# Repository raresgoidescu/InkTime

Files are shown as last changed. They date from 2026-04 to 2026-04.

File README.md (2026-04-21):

<!-- Copyright GOIDESCU Rareș-Ștefan 2026 -->

# InkTime

InkTime is a proper solution for the people that can't be bothered to charge their watch daily. This is a beginner's attempt at implementing it. Please see [the disclaimer and the license](#trademark-disclaimer) notice.

## Block Diagram

Block Diagram Image

## Bill of Materials

| Part / Value | Refs | Qty | Procurement | Datasheet |
| :--- | :--- | :---: | :--- | :--- |
| **Active ICs & Semiconductors** | | | | |
| nRF52840-QFAA Microcontroller | U1 | 1 | [DigiKey](https://www.digikey.be/en/products/detail/nordic-semiconductor-asa/NRF52840-QFAA-F-R/15929812) | [DS](https://www.nordicsemi.com/Products/nRF52840) |
| BMA423 Triaxial Accelerometer | IC3 | 1 |[Mouser 262-BMA423](https://eu.mouser.com/ProductDetail/Bosch-Sensortec/BMA423?qs=HXFqYaX1Q2xC%252BSgeGoX3mg%3D%3D) | [DS](https://watchy.sqfmi.com/assets/files/BST-BMA423-DS000-1509600-950150f51058597a6234dd3eaafbb1f0.pdf) |
| BQ25180YBGR Li-Ion Charger | IC1 | 1 |[Mouser 595-BQ25180YBGR](https://eu.mouser.com/ProductDetail/Texas-Instruments/BQ25180YBGR?qs=doiCPypUmgEWjAK%252BJAX6Tw%3D%3D) | [DS](https://www.ti.com/product/BQ25180) |
| DRV2605YZFR Haptic Driver | IC2 | 1 | [Mouser](https://eu.mouser.com/ProductDetail/Texas-Instruments/DRV2605YZFR?qs=9Zb5cNRUa0Ym539PjgFm3g%3D%3D) | [DS](https://www.ti.com/product/DRV2605) |
| MAX17048G+T10 Fuel Gauge | U3 | 1 | [DigiKey](https://www.digikey.com/en/products/detail/analog-devices-inc-maxim-integrated/MAX17048G-T10/3758921) | [DS](https://www.analog.com/en/products/max17048.html) |
| RT6160AWSC Buck-Boost DC-DC | IC9 | 1 |[Mouser 835-RT6160AWSC](https://eu.mouser.com/ProductDetail/Richtek/RT6160AWSC?qs=amGC7iS6iy%2FLd9PSoixZXQ%3D%3D) | [DS](https://www.richtek.com/Products/Switching%20Regulators/Buck-Boost%20Converter/RT6160A) |
| USBLC6-2SC6Y ESD Protection | D3 | 1 | [DigiKey](https://www.digikey.com/en/products/detail/stmicroelectronics/USBLC6-2SC6Y/2819177) | [DS](https://www.st.com/en/protections-and-emi-filters/usblc6-2.html) |
| MBR0530 Schottky Diode | D2, D4, D5 | 3 | [Mouser](https://eu.mouser.com/c/semiconductors/discrete-semiconductors/diodes-rectifiers/schottky-diodes-rectifiers/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) | [DS](https://www.onsemi.com/pdf/datasheet/mbr0530t1-d.pdf) |
| DMG2305UX-7 P-CH MOSFET 20V/4.2A | Q1 | 1 | [Mouser](https://ro.mouser.com/ProductDetail/Diodes-Incorporated/DMG2305UX-7?qs=L1DZKBg7t5F%2FNBHrjfxC%252Bg%3D%3D) | [DS](https://www.diodes.com/assets/Datasheets/DMG2305UX.pdf) |
| SI1308EDL-T1-GE3 N-CH MOSFET 30V/1.5A | Q3 | 1 | [Mouser](https://eu.mouser.com/ProductDetail/Vishay-Semiconductors/SI1308EDL-T1-GE3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) |[DS](https://www.vishay.com/docs/63399/si1308edl.pdf) |
| **Connectors & Electromechanical** | | | | |
| 2450AT18B100E 2.45 GHz Antenna | ANT1 | 1 | [Mouser 609-2450AT18B100E](https://www.mouser.co.uk/ProductDetail/Johanson-Technology/2450AT18B100E?qs=yCnrNFeXz%252Bh5MFsFIXGZGA%3D%3D) | [DS](https://www.johansontechnology.com/datasheets/2450AT18B100/2450AT18B100.pdf) |
| 503480-2400 24-pin FPC 0.5 mm | J1 | 1 |[Mouser 538-503480-2400](https://eu.mouser.com/ProductDetail/Molex/503480-2400?qs=OAhjpuo3Vu7efIoxFh9AOw%3D%3D) | [DS](https://www.molex.com/en-us/products/part-detail/5034802400?display=pdf) |
| KH-TYPE-C-16P USB Type-C 16-pin | J4 | 1 | [xonelec.com](https://www.xonelec.com/mpn/kinghelm/khtypec16p) | [DS](https://xonstorage.z8.web.core.windows.net/pdf/kinghelm_khtypec16p_xonjuly20_20_link.pdf) |
| TC2030-IDC 6-pin Debug Adapter | J2 | 1 | [Tag-Connect](https://www.tag-connect.com/product/tc2030-idc-6-pin-tag-connect-plug-of-nails-spring-pin-cable-with-legs) | [DS](https://www.tag-connect.com/wp-content/uploads/bsk-pdf-manager/2019/12/TC2030-IDC-Datasheet-Rev-B.pdf) |
| EVP-AKE31A Tactile Button | SW_DN, SW_ENT, SW_UP | 3 |[Mouser](https://eu.mouser.com/ProductDetail/Panasonic/EVP-AKE31A?qs=EU6FO9ffTwe%252BJzX5LvvHqA%3D%3D) | [DS](https://www.tme.eu/Document/7d6137f818fadb8daa876cedb29b6731/EVPAKseries.pdf) |
| **Inductors** | | | | |
| FTC252012SR47MBCA 0.47 µH | L7 | 1 |[LCSC C5832368](https://www.lcsc.com/product-detail/C5832368.html) | [DS](https://www.lcsc.com/datasheet/C5832368.pdf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) |
| 744043680 68 µH | L5 | 1 |[Mouser](https://eu.mouser.com/ProductDetail/Wurth-Elektronik/744043680?qs=PGXP4M47uW6VkZq%252BkzjrHA%3D%3D) | [DS](https://www.we-online.com/katalog/datasheet/744043680.pdf) |
| **Passives** | | | | |
| 12 pF 0201 (HFXO/LFXO load caps) | C1, C2, C17, C18 | 4 | Generic 0201 | - |
| 100 nF 0201 decoupling | C5, C7, C8, C12, C19 | 5 | Generic 0201 | - |
| 1 µF 0201[GRM011R60J152KE01L](https://www.snapeda.com/parts/GRM011R60J152KE01L/Murata/view-part/) | C29–C32, C37, C38 | 6 | Murata / Mouser | - |
| 0.1 µF 0201[GRM011R60J152KE01L](https://www.snapeda.com/parts/GRM011R60J152KE01L/Murata/view-part/) | C23, C27, C34, C42 | 4 | Murata / Mouser | - |
| 10 µF 0402 | C24, C39, C1-EP-DR | 3 | Generic 0402 | - |
| 22 µF 0402 | C25, C33 | 2 | Generic 0402 | - |
| 1 µF/50V 0402 (EPD drive) | EPD_C1/2/6–12 | 9 | Generic 0402 | - |
| 3.3 kΩ 0201 (I2C pull-ups) | R17, R18 | 2 | Generic 0201 | - |
| 5.1 kΩ 0201 (USB CC) | R1_USB, R2_USB | 2 | Generic 0201 | - |
| 10 kΩ 0201 (button pull-ups, misc) | R5, R7, R8, R9, R2_EP_DR, R_PWR_EPD | 6 | Generic 0201 | - |
| 0 Ω 0201 (DNP jumpers) | R2, R3, R4 | 3 | Generic 0201 | - |

## Hardware Description

### Power Management

**BQ25180YBGR** charges the LiPo from USB (5V). `PMIC_INT` alerts the MCU to faults and status changes. Q1 provides reverse-polarity protection on the VBUS path.

**RT6160AWSC** generates the 3V3 rail via a buck-boost topology, required because battery voltage (3V–4V2) straddles the 3V3 output. Switching node uses an inductor; output is filtered by capacitors. Controlled via I2C and a GPIO enable pin.

**MAX17048G+T10** estimates battery SoC over I2C using the ModelGauge algorithm, eliminating the need for a power-wasting current-sense resistor. The `ALERT` pin fires when the SoC drops below a configurable threshold.

**MBR0530 diodes** (D2, D4, D5) are arranged to steer power between USB, the battery, and the EPD drive rail to prevent back-feeding across power domains.

### Microcontroller

64 MHz Cortex-M4F, 1 MB Flash, 256 KB RAM, Bluetooth 5.0 LE, USB 2.0 FS. Peripherals used:

- **Power** - The internal DC-DC regulator is enabled via dedicated LC matching to step down the 3V3 rail internally, drastically reducing the active power footprint of the CPU and radio.
- **SPIM3** - E-Paper display (MOSI, SCK + 4 control GPIOs)
- **TWIM0** - shared I2C bus (BMA423, BQ25180, MAX17048, DRV2605, RT6160A)
- **USB** - firmware update / serial via dedicated D+/D− pads through USBLC6 ESD protection
- **RTC0** - timekeeping in sleep, clocked from 32.768 kHz LFXO
- **Radio** - Bluetooth LE for phone time sync

### Clocks

- X1 (32 MHz) - HFXO for CPU and radio. 12 pF load caps C1, C2 placed adjacent.
- X2 (32.768 kHz) - LFXO for RTC. Pins P0.00/XL1 and P0.01/XL2. 12 pF load caps C17, C18.

### Antenna

The 2450AT18B100E chip antenna sits at the board edge with the full copper/trace keep-out zone underneath per the datasheet.
It connects via a matching network.

### Display (SPI)

Molex 503480-2400 24-pin 0.5 mm FPC connector (J1) on the left board edge.
Interface: MOSI, SCK, EPD_CS, EPD_DC, EPD_RST, EPD_BUSY over SPIM3.
The on-board boost drive circuit generates the positive and negative high-voltage rails needed for pixel switching.
SJ1 solder jumper selects the EPD panel variant.

### IMU (I2C)

Step counting, tilt, tap detection, etc.

### Haptics (I2C)

DRV2605YZFR ERM/LRA haptic driver for physical notification feedback.

### Buttons

Three EVP-AKE31A side-entry tactile switches. Debounced via hardware using capacitors (C29–C32 series) and 10 kΩ pull-ups (R5, R7, R8) to ensure clean interrupts waking the MCU from deep sleep.

### Debug Interface

Tag-Connect 6-pin pogo footprint (J2). Signals: SWDIO, SWDCLK, SWO, RESET, VCC, GND.

## nRF52840 Pin Assignment

| Pin | Net | Peripheral | Notes |
| :--- | :--- | :--- | :--- |
| P0.00/XL1 | `XL1` | Crystal X2 | 32.768 kHz LFXO in |
| P0.01/XL2 | `XL2` | Crystal X2 | 32.768 kHz LFXO out |
| XC1, XC2 | `XC1`, `XC2` | Crystal X1 | 32 MHz HFXO |
| P0.06 | `SDA` | IC1, IC2, IC3, U3, IC9 | I2C |
| P0.07 | `SCL` | IC1, IC2, IC3, U3, IC9 | I2C |
| P0.08 | `IMU_INT1` | IMU (BMA421)	Interrupt 1 |
| P0.11	| `PMIC_INT` | LiPo Charger | Fault interrupt |
| P0.12	| `HAPTIC_EN`	| Haptics | Haptics enable |
| P0.13 | `P0.13` | SW_UP | Button |
| P0.14 | `P0.14` | SW_ENT | Button |
| P0.15	| `EPD_DC` | Display D/C |
| P0.16	| `EPD_RST` | Display reset |
| P0.17 | `EPD_BUSY` | Display | Busy status |
| P0.18/RESET | `RESET` | TC2030 J2, pull-up | system reset |
| SWDCLK | `SWDCLK` | TC2030 J2 | SWD clock |
| SWDIO | `SWDIO` | TC2030 J2 | SWD data |
| P1.00 | `SWO` | TP | SWO trace output |
| P1.02 | `P1.02` | SW_DN | Button |
| P1.08 | `IMU_INT2` | IMU | Interrupt 2 |
| P1.10 | `ALERT` | Fuel Gauge | SoC alert |
| D+ | `D+` | USB-C J4 via D3 | USB FS data + |
| D− | `D−` | USB-C J4 via D3 | USB FS data − |
| VBUS | `VBUS` | J4 / R1_USB+R2_USB divider | 5 V bus |
| ANT |	`RF` | 2.4 GHz antenna | Antenna feed |

## Power Consumption Estimates

| Mode | Dominant consumers | Est. current | Battery life (300 mAh) |
| :--- | :--- | ---: | ---: |
| Deep sleep (Static display, BLE off) | nRF52840 RTC + BMA423 sleep + MAX17048 + quiescent ICs | ~120 µA | ~104 days |
| Active (1 EPD refresh/min + BLE adv) | CPU active + Radio TX/RX + EPD boost circuit averaged | ~5–6 mA | ~50 hours |
| Mixed realistic use | Mostly deep sleep, periodic wake on wrist gesture / button press | - | **~7–14 days** |

## Design Logs

- Had to manually approve via in pad overlaps.
- Had to apply neck down to some segments of the power routes, reducing the width to 0.2675 mm (from 0.3 mm).
- Matched lenght for differential lines and symmetric configurations for the crystals.

## PCB Renders

### Top Layer

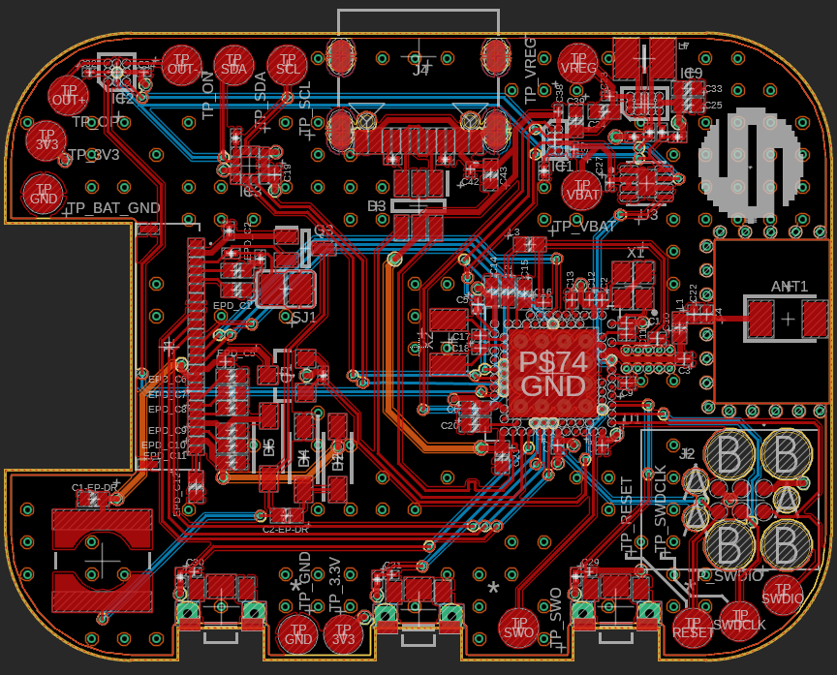
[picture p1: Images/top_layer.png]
PCB Top Layer


### Polygon Pours

| Top | Bottom |
|---|---|
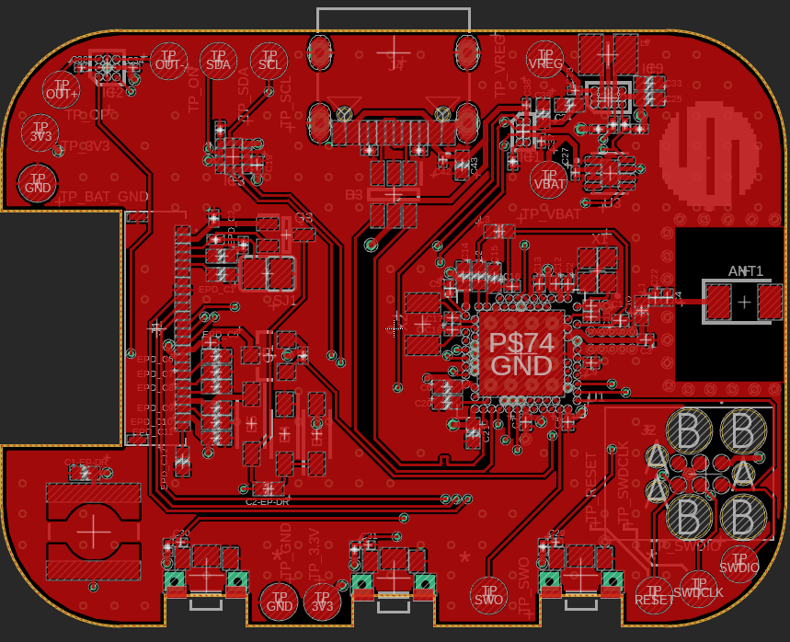
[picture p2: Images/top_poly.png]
top_poly
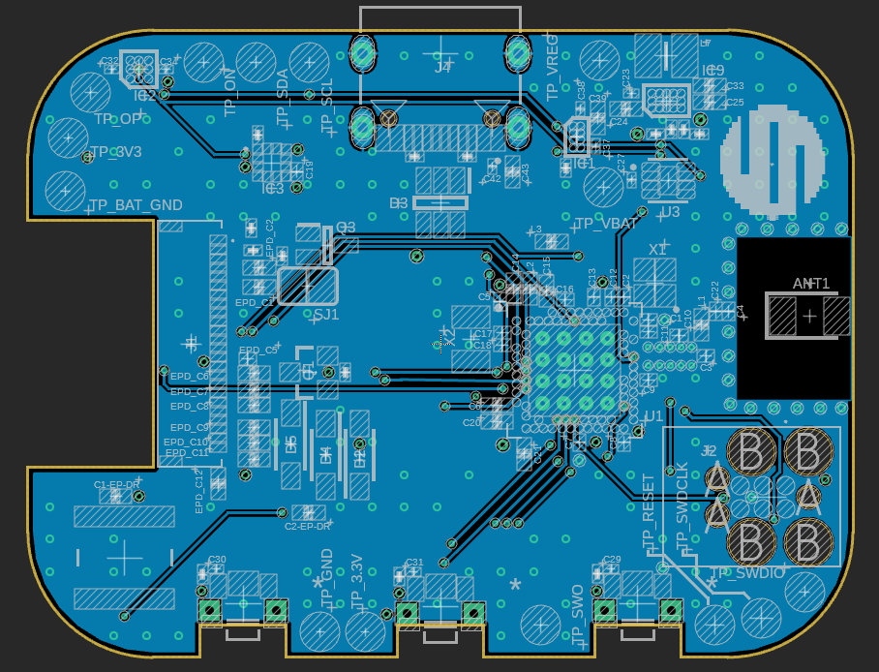
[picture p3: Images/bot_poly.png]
bot_poly
|  |  |

| GND | Power |
|---|---|
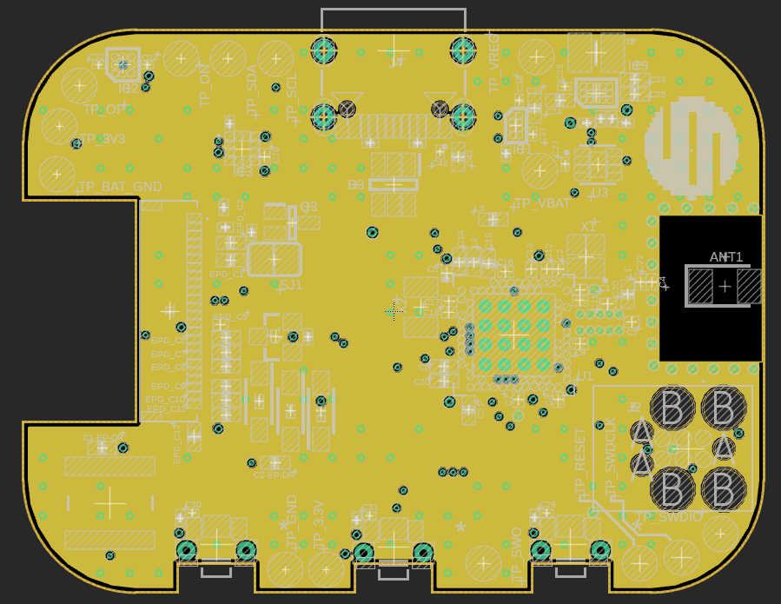
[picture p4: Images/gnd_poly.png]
gnd_poly
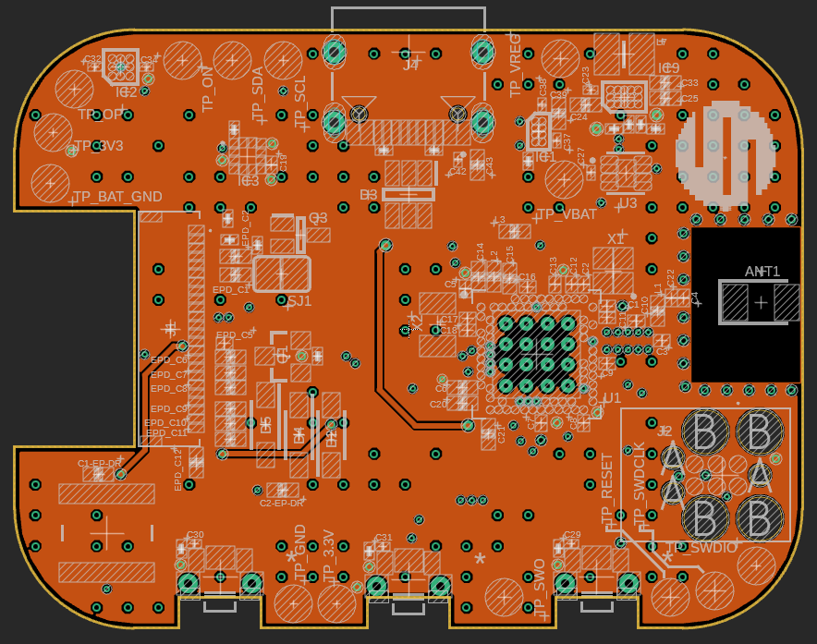
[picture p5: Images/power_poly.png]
power_poly
|  |  |

## Exploded View

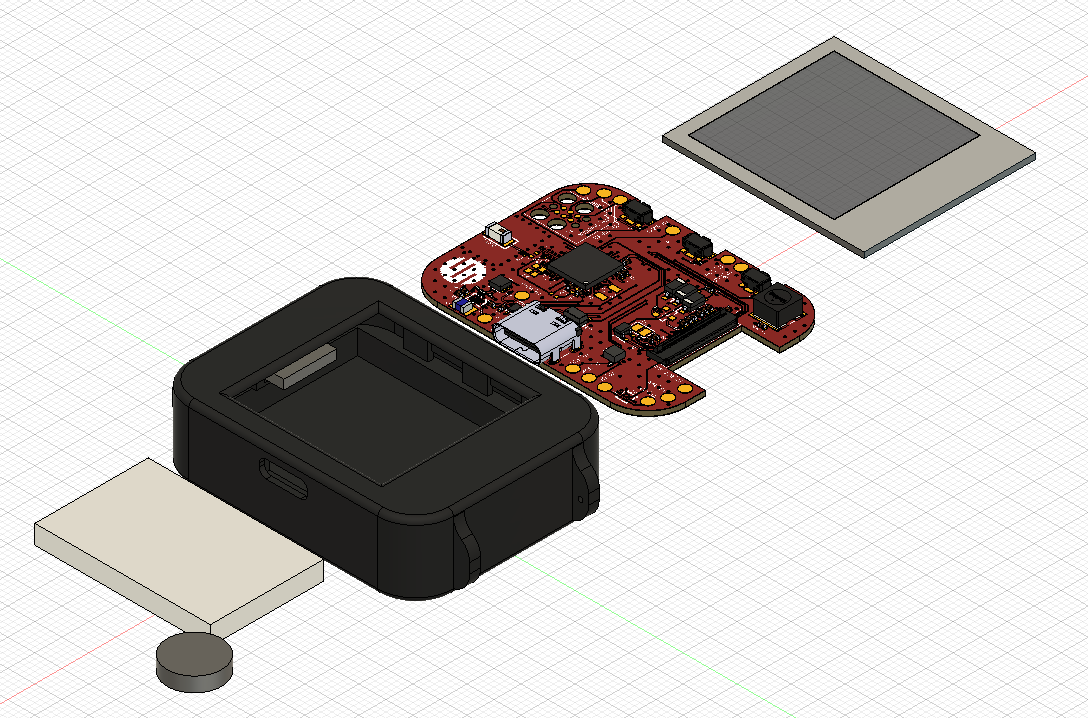
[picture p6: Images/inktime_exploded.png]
InkTimeExploded


## Trademark Disclaimer

This project includes a reproduction of the Viltrumite logo on the PCB silkscreen.

- The Viltrumite logo is trademark of Image Comics and/or its creators.
- This project is non-commercial and is not affiliated with, endorsed by, or sponsored by Image Comics or the Invincible franchise.
- The [CERN-OHL-S v2.0](LICENSE) license governs the electronic design files only and does not grant any rights to the Viltrumite trademark or associated artwork.

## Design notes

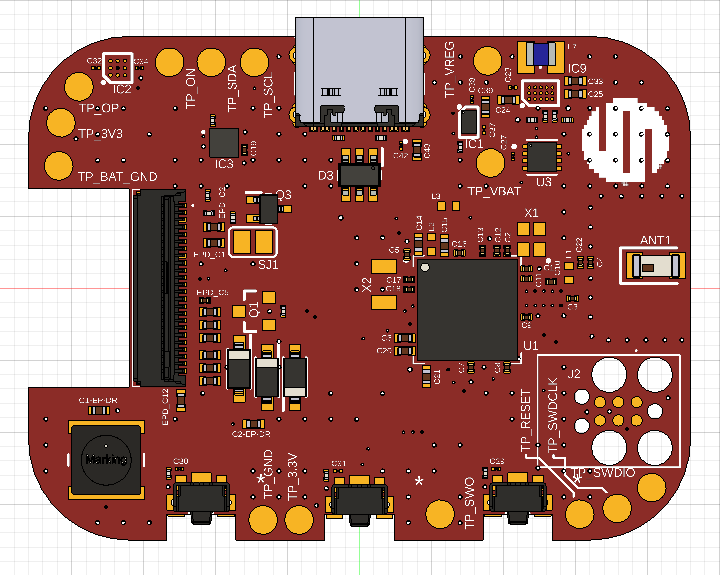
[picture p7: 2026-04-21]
Images/board-top.png

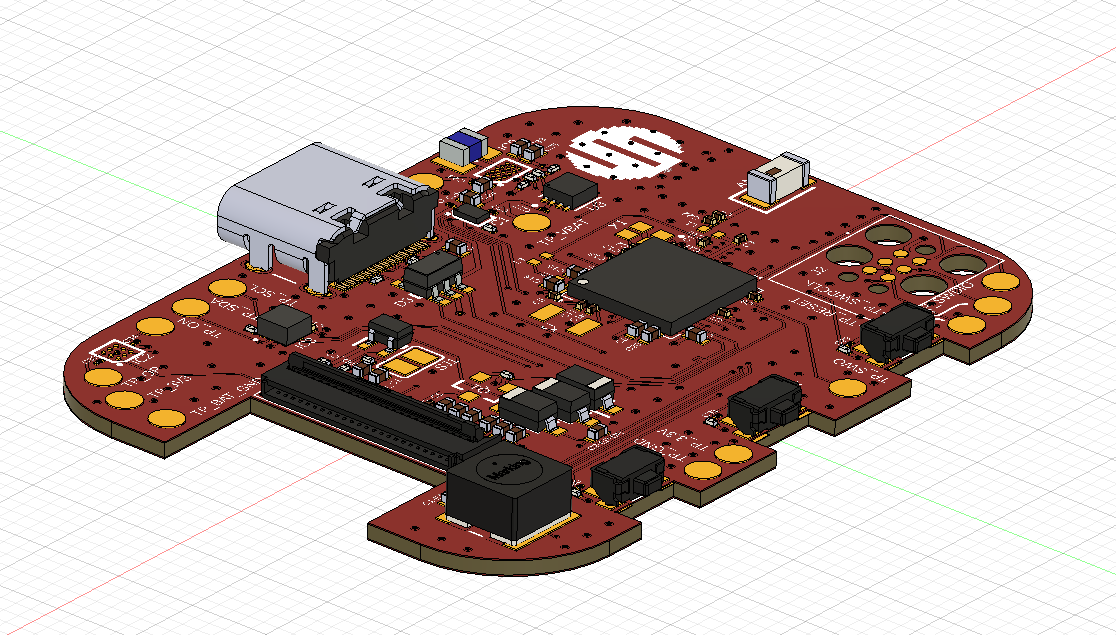
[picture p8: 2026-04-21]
Images/board-side.png

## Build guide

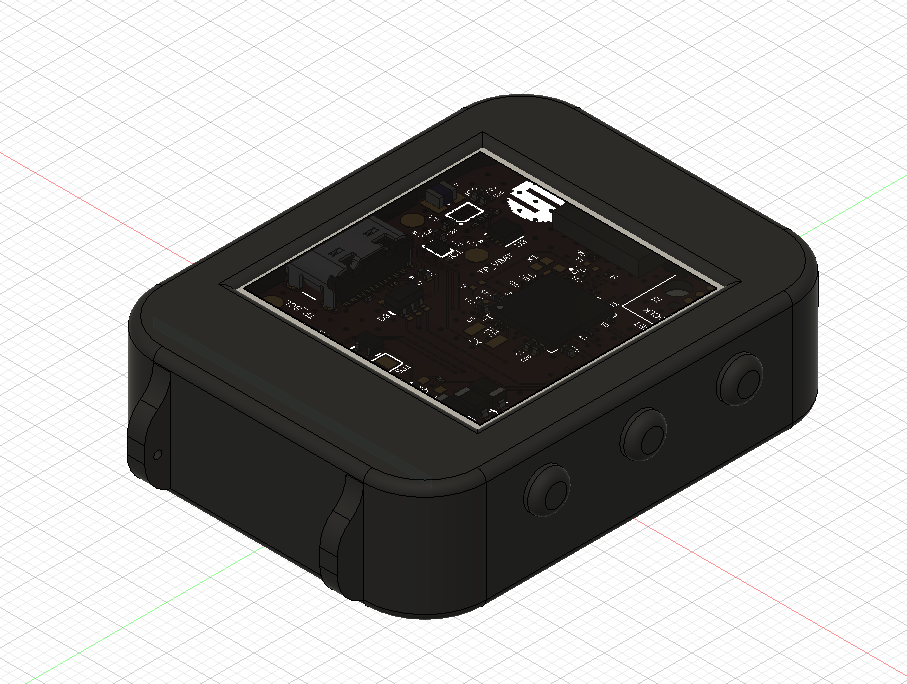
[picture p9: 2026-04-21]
Images/complete_assembly.png

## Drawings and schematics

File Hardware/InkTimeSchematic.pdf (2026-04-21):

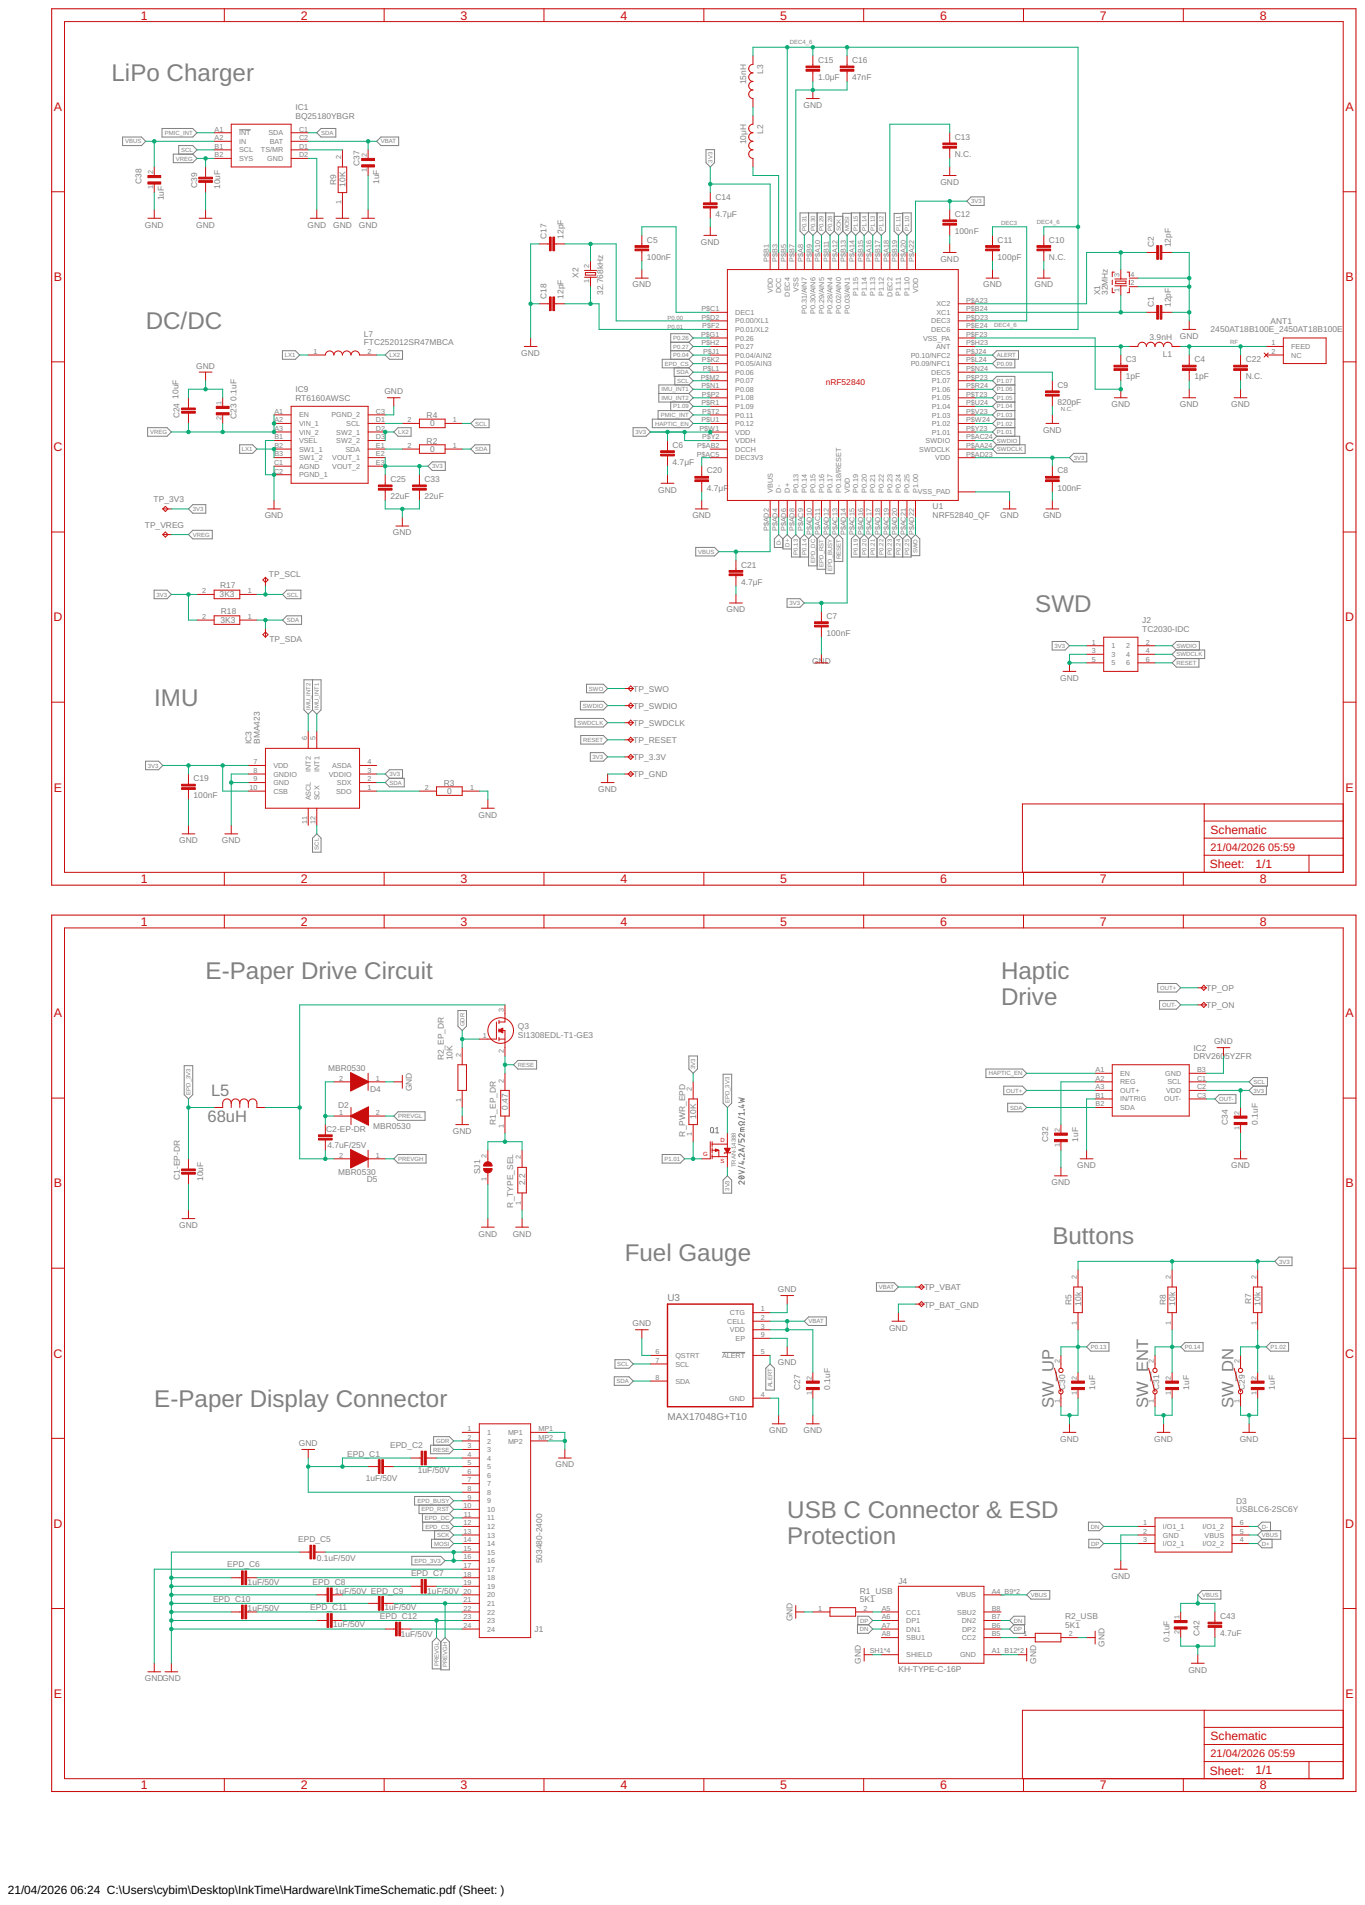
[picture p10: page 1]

1uF GND GND GND GND GND

EPD_C7 18

1uF/50V EPD_C8 | 19

EPD_C10 | | 21

1uF/50V EPD_C11 | 1uF/50V | 22

EPD_C12 | 23

21/04/2026 06:24 C:\Users\cybim\Desktop\InkTime\Hardware\InkTimeSchematic.pdf (Sheet: )

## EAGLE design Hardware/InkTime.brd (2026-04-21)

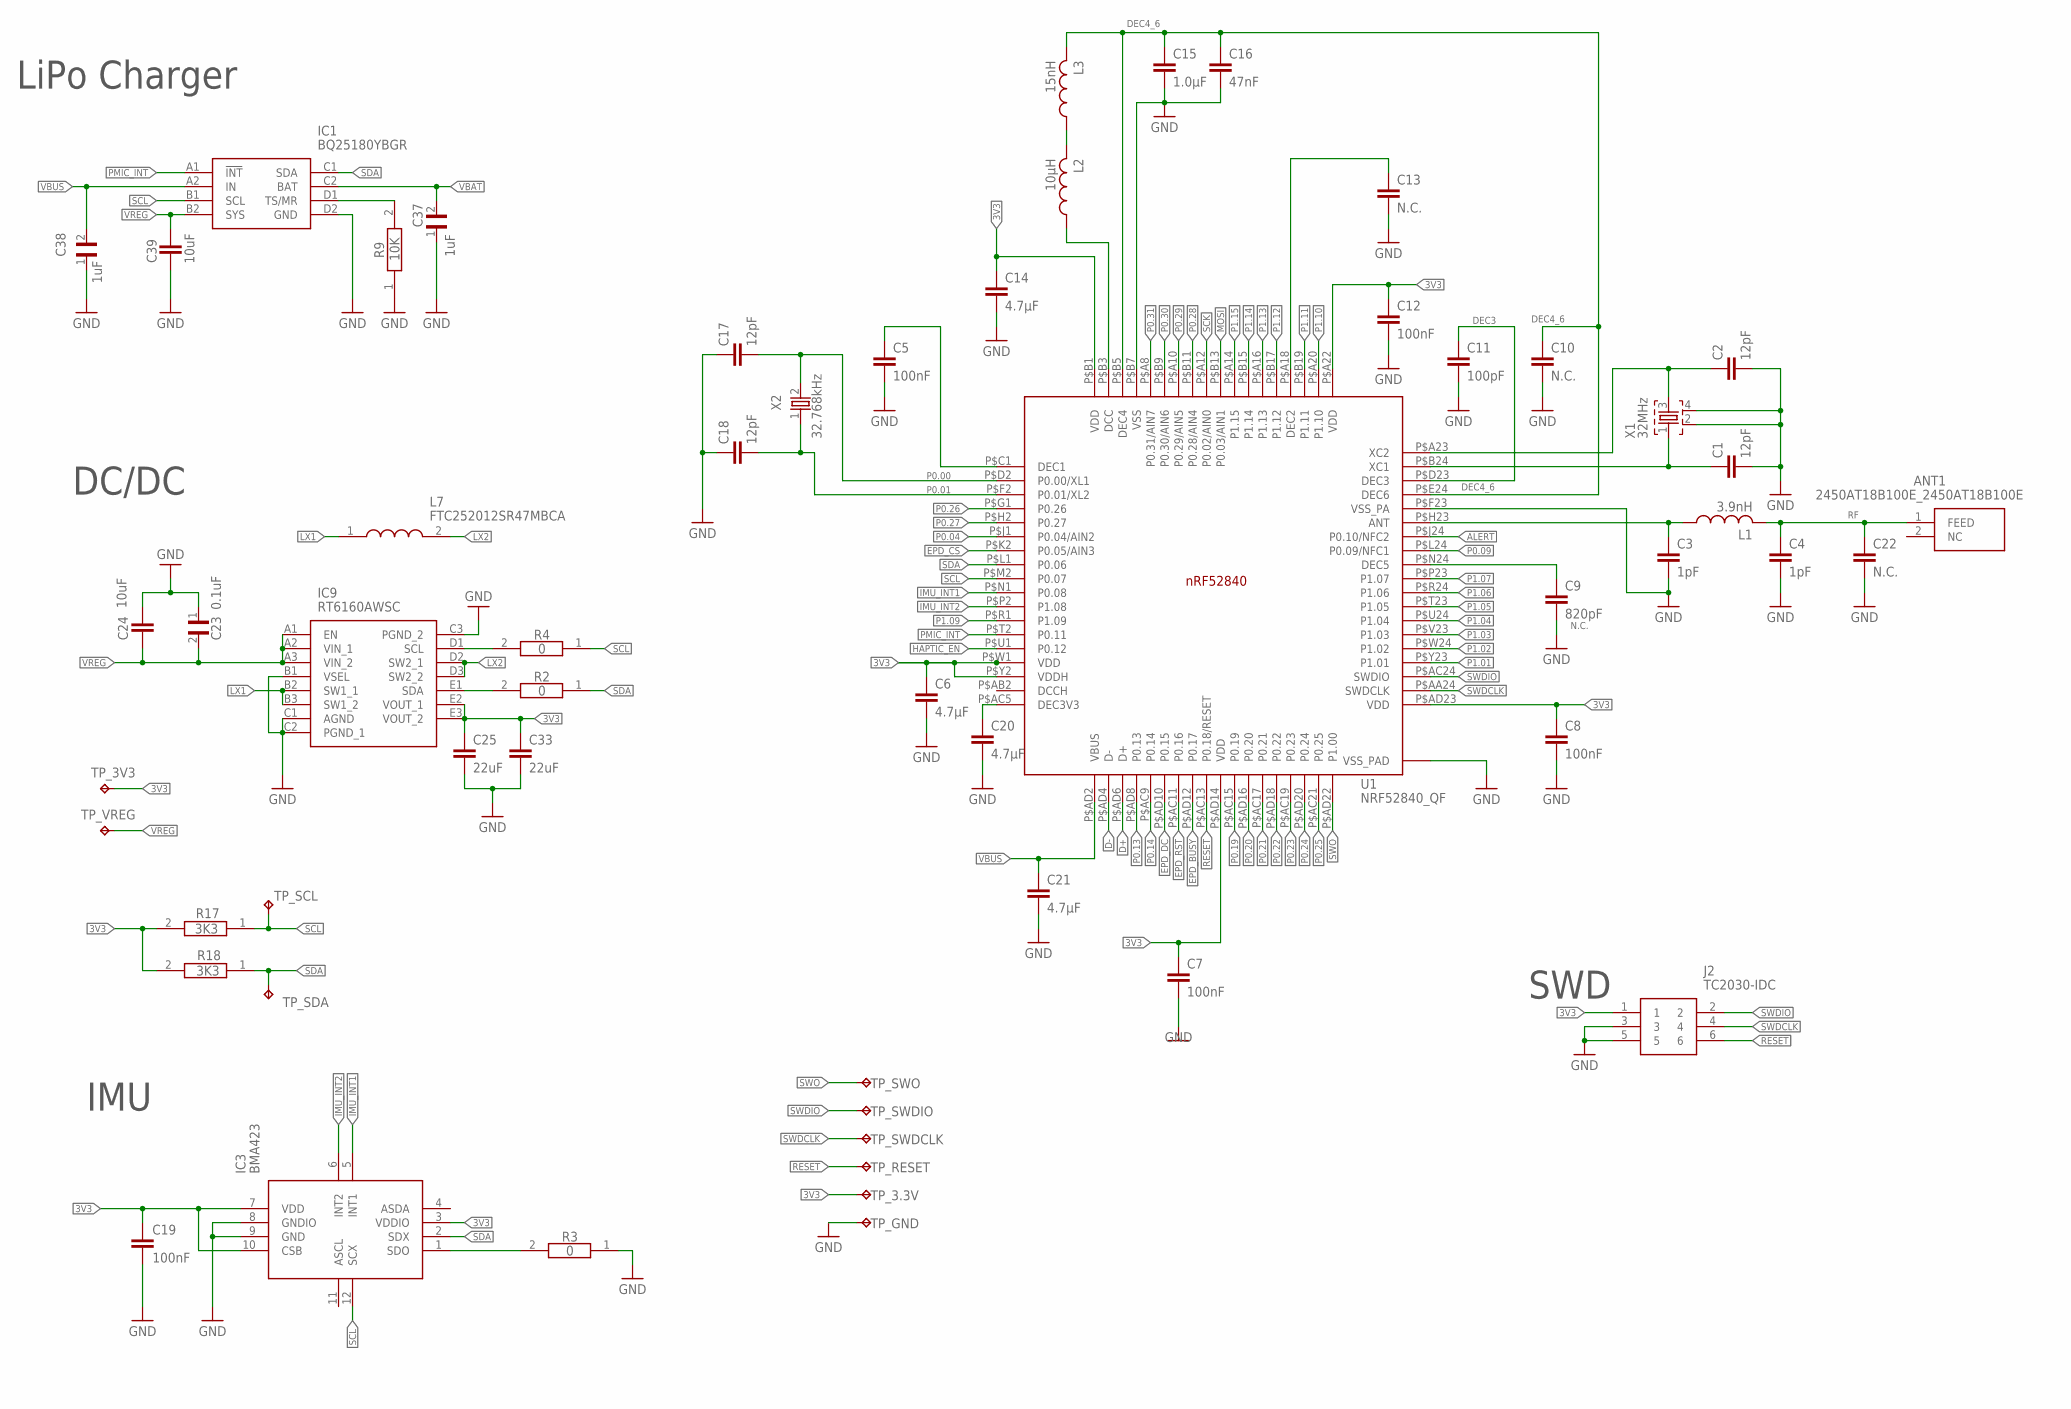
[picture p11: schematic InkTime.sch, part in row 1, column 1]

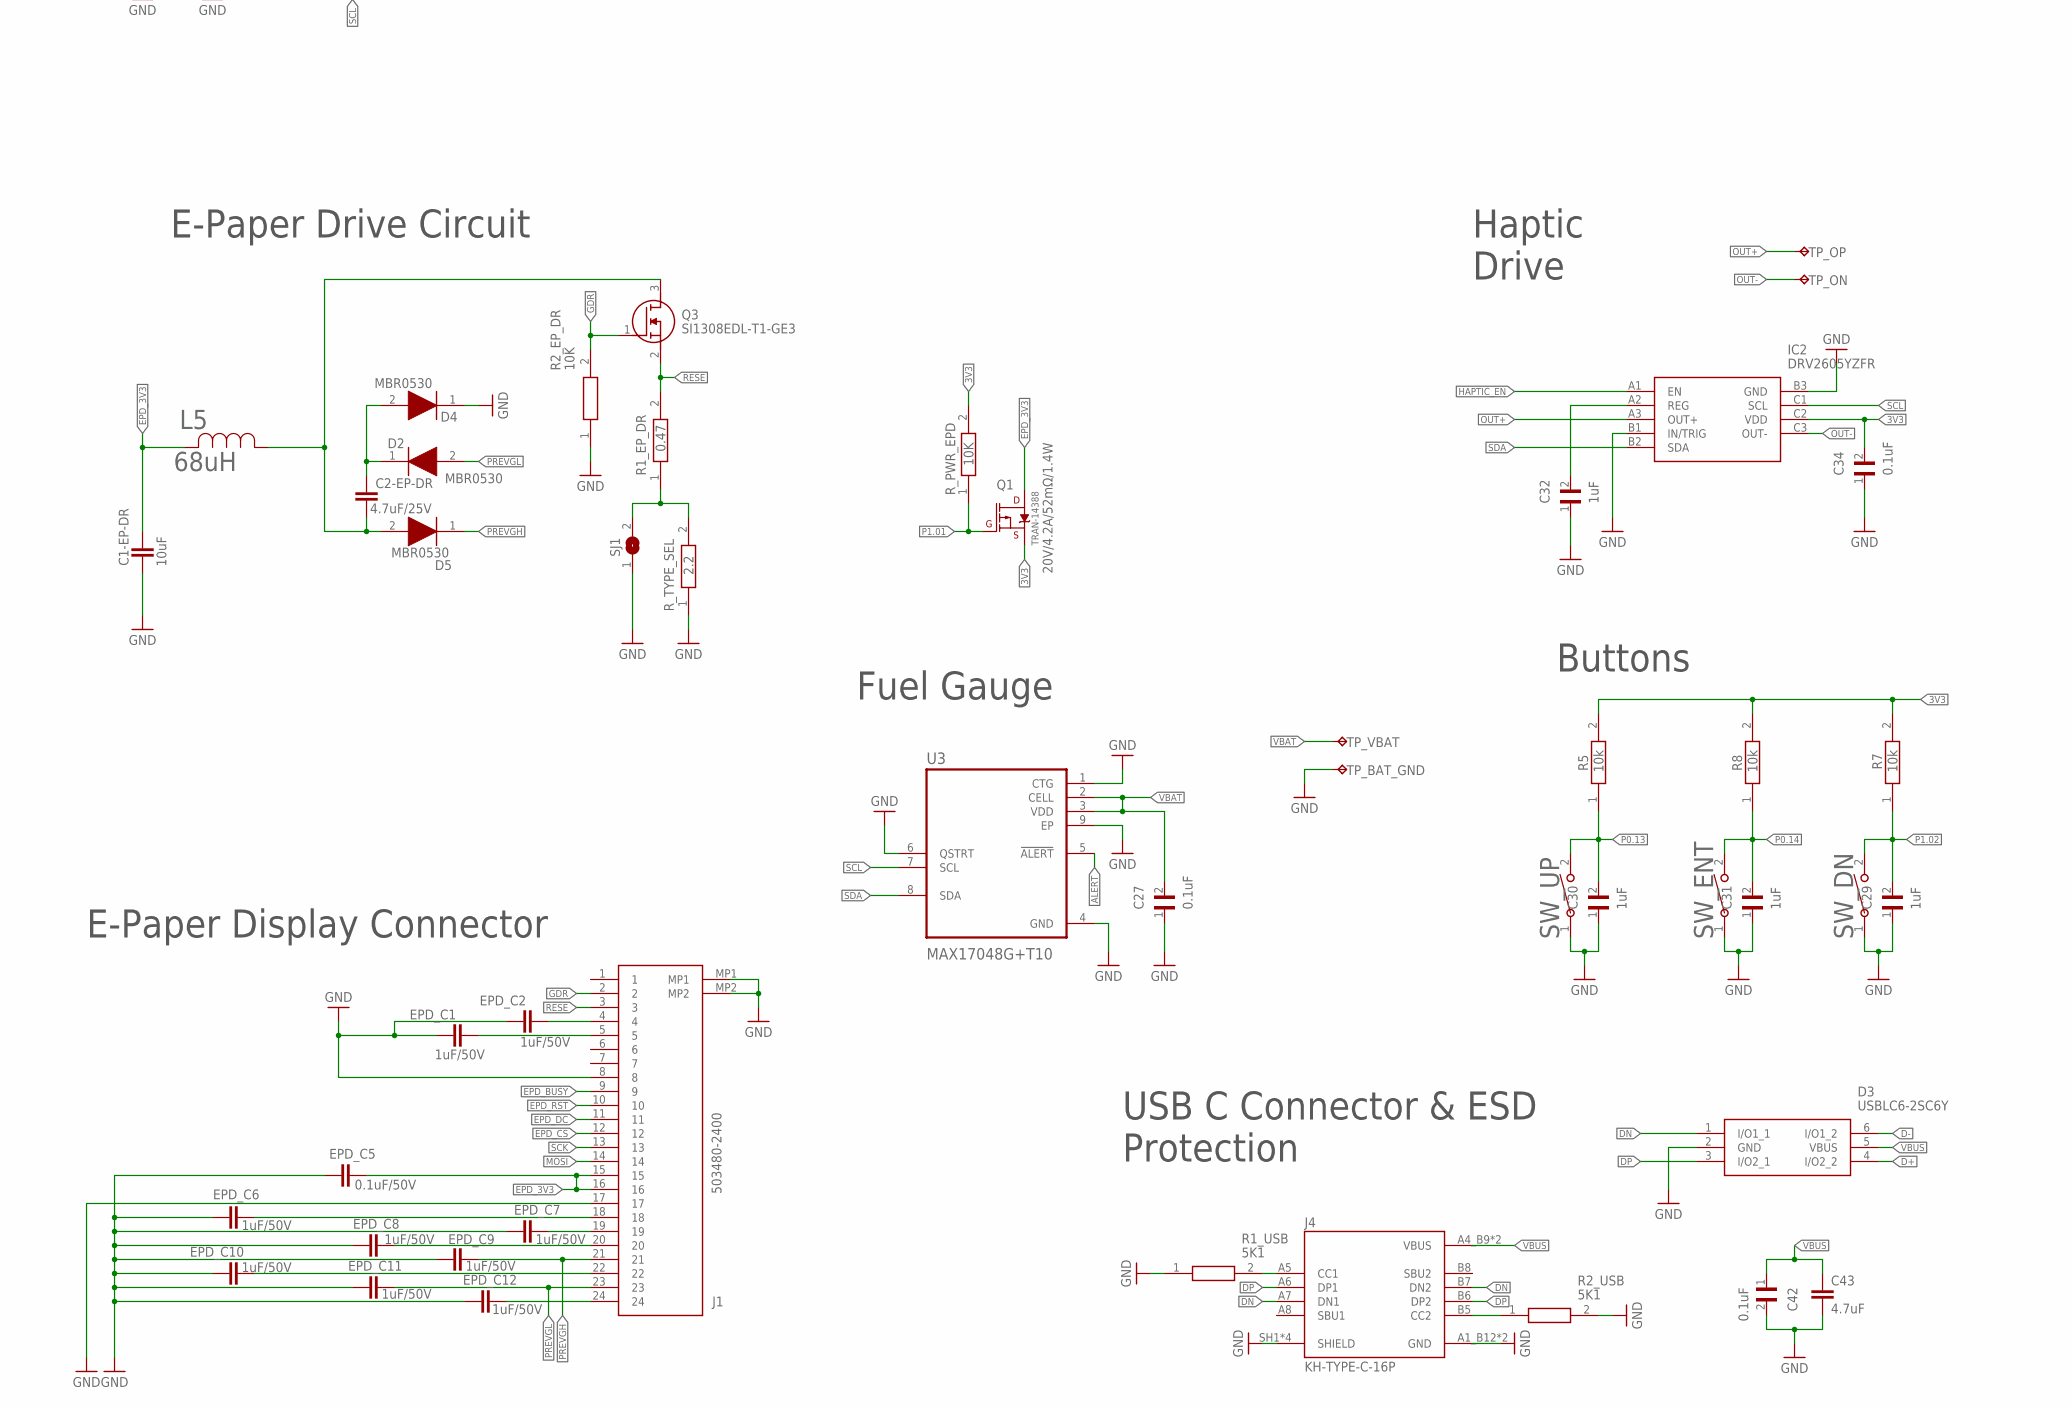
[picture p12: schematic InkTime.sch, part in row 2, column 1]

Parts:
ANT1: 2450AT18B100E_2450AT18B100E; 2450AT18B100E_ANTC3216X140N
C1, C2, C17, C18: 12pF; NORDIC_NRF_3_RESC0201_L
C1-EP-DR, C24, C39: 10uF; NORDIC_NRF_3_RESC0402_L
C2-EP-DR: 4.7uF/25V; NORDIC_NRF_3_RESC0402_L
C3, C4: 1pF; NORDIC_NRF_3_RESC0201_L
C5, C7, C8, C12, C19: 100nF; NORDIC_NRF_3_RESC0201_L
C6, C14, C20, C21: 4.7μF; NORDIC_NRF_3_RESC0402_L
C9: 820pF; NORDIC_NRF_3_RESC0201_L
C10, C13, C22: N.C.; NORDIC_NRF_3_RESC0201_L
C11: 100pF; NORDIC_NRF_3_RESC0201_L
C15: 1.0μF; NORDIC_NRF_3_RESC0402_L
C16: 47nF; NORDIC_NRF_3_RESC0201_L
C23, C27, C34, C42: 0.1uF; GRM011R60J152KE01L_2_CAPC0201X13N
C25, C33: 22uF; NORDIC_NRF_3_RESC0402_L
C29, C30, C31, C32, C37, C38: 1uF; GRM011R60J152KE01L_2_CAPC0201X13N
C43: 4.7uF; NORDIC_NRF_3_RESC0402_L
D2, D4, D5: MBR0530; ESP32_C6_LIBRARY_5_SOD3716X135N
D3: USBLC6-2SC6Y; ESP32_C6_LIBRARY_3_SOT95P280X145-6N
EPD_C1, EPD_C2, EPD_C6, EPD_C7, EPD_C8, EPD_C9, EPD_C10, EPD_C11, EPD_C12: 1uF/50V; NORDIC_NRF_3_RESC0402_L
EPD_C5: 0.1uF/50V; NORDIC_NRF_3_RESC0201_L
IC1: BQ25180YBGR; BQ25180YBGR_BGA8C40P2X4_100X155X50
IC2: DRV2605YZFR; DRV2605YZFR_BGA9C50P3X3_144X144X62
IC3: BMA423; BMA423_BMA423
IC9: RT6160AWSC; RT6160AWSC_BGA15C40P3X5_140X230X60
J1: 503480-2400; 503480-2400_5034802400
J2: TC2030-IDC; TC2030-IDC_TC2030IDC
J4: KH-TYPE-C-16P; KH-TYPE-C-16P_KINGHELM_KH-TYPE-C-16P
L1: 3.9nH; NORDIC_NRF_2_RESC0402_L
L2: 10μH; NORDIC_NRF_2_RESC0402_L
L3: 15nH; NORDIC_NRF_2_RESC0402_L
L5: 68uH; ESP32_C6_LIBRARY_2_IND_4828-WE-TPC_WRE
L7: FTC252012SR47MBCA; MLP2016SR47MT0S1_INDC2016X100N
Q1: 20V/4.2A/52mΩ/1.4W; ESP32_C6_LIBRARY_4_ESP32_C6_LIBRARY_4_ESP32_C6_LIBRARY_4_ES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
Q3: SI1308EDL-T1-GE3; ESP32_C6_LIBRARY_6_SOT65P210X110-3N
R1_EP_DR: 0.47; ERA-1AEB3401C_0201
R1_USB, R2_USB: 5K1; ERA-1AEB3401C_0201
R2, R3, R4: 0; ERA-1AEB3401C_0201
R2_EP_DR, R9: 10K; ERA-1AEB3401C_0201
R5, R7, R8: 10k; ERA-1AEB3401C_0201
R17, R18: 3K3; ERA-1AEB3401C_0201
R_PWR_EPD: 10K; ERA-1AEB3401C_0201
R_TYPE_SEL: 2.2; ERA-1AEB3401C_0201
SJ1: ESP32_C6_LIBRARY_7_JUMPER_SJ
SW_DN: 2025-10-22_07-23-44_LIBRARY_EVP-AKE31ASW_EVP-AKE3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; 2025-10-22_07-23-44_LIBRARY_SW_EVP-AKE31A_PAN
SW_ENT: 2025-10-22_07-23-44_LIBRARY_EVP-AKE31ASW_EVP-AKE3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; 2025-10-22_07-23-44_LIBRARY_SW_EVP-AKE31A_PAN
SW_UP: 2025-10-22_07-23-44_LIBRARY_EVP-AKE31ASW_EVP-AKE3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; 2025-10-22_07-23-44_LIBRARY_SW_EVP-AKE31A_PAN
TP_3.3V, TP_3V3: HECTOR_WATCH_1_TPTP20R; HECTOR_WATCH_1_TP20R
TP_BAT_GND: HECTOR_WATCH_1_TPTP20R; HECTOR_WATCH_1_TP20R
TP_GND: HECTOR_WATCH_1_TPTP20R; HECTOR_WATCH_1_TP20R
TP_ON: HECTOR_WATCH_1_TPTP20R; HECTOR_WATCH_1_TP20R
TP_OP: HECTOR_WATCH_1_TPTP20R; HECTOR_WATCH_1_TP20R
TP_RESET: HECTOR_WATCH_1_TPTP20R; HECTOR_WATCH_1_TP20R
TP_SCL: HECTOR_WATCH_1_TPTP20R; HECTOR_WATCH_1_TP20R
TP_SDA: HECTOR_WATCH_1_TPTP20R; HECTOR_WATCH_1_TP20R
TP_SWDCLK: HECTOR_WATCH_1_TPTP20R; HECTOR_WATCH_1_TP20R
TP_SWDIO: HECTOR_WATCH_1_TPTP20R; HECTOR_WATCH_1_TP20R
TP_SWO: HECTOR_WATCH_1_TPTP20R; HECTOR_WATCH_1_TP20R
TP_VBAT: HECTOR_WATCH_1_TPTP20R; HECTOR_WATCH_1_TP20R
TP_VREG: HECTOR_WATCH_1_TPTP20R; HECTOR_WATCH_1_TP20R
U1: NRF52840_QF; NORDIC_NRF_4_AQFN50P700X700X85_HS-74N
U3: MAX17048G+T10; ESP32_C6_LIBRARY_SON50P200X200X80-9N
X1: 32MHz; NORDIC_NRF_BT-XTAL_2016_N
X2: 32.768kHz; NORDIC_NRF_1_XTAL_3215_N

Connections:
3V3: C6.1, C7.1, C8.1, C12.1, C14.1, C19.2, C25.1, C33.1, C34.2, IC2.C2 (VDD), IC3.3 (VDDIO), IC3.7 (VDD), IC3.10 (CSB), IC9.E2 (VOUT_1), IC9.E3 (VOUT_2), J2.1, Q1.2 (S), R5.2, R7.2, R8.2, R17.2, R18.2, R_PWR_EPD.2, TP_3.3V.TP, TP_3V3.TP, U1.P$A22 (VDD), U1.P$AD14 (VDD), U1.P$AD23 (VDD), U1.P$B1 (VDD), U1.P$W1 (VDD), U1.P$Y2 (VDDH)
ALERT: U1.P$J24 (P0.10/NFC2), U3.5 (!ALERT)
D+: D3.4 (I/O2_2), U1.P$AD6 (D+)
D-: D3.6 (I/O1_2), U1.P$AD4 (D-)
DEC3: C11.1, U1.P$D23 (DEC3)
DEC4_6: C10.1, C15.1, C16.1, L3.2, U1.P$B5 (DEC4), U1.P$E24 (DEC6)
DN: D3.1 (I/O1_1), J4.A7 (DN1), J4.B7 (DN2)
DP: D3.3 (I/O2_1), J4.A6 (DP1), J4.B6 (DP2)
EPD_3V3: C1-EP-DR.1, EPD_C5.2, J1.15, J1.16, L5.2, Q1.3 (D)
EPD_BUSY: J1.9, U1.P$AD12 (P0.17)
EPD_CS: J1.12, U1.P$K2 (P0.05/AIN3)
EPD_DC: J1.11, U1.P$AD10 (P0.15)
EPD_RST: J1.10, U1.P$AC11 (P0.16)
GDR: J1.2, Q3.1 (G), R2_EP_DR.2
GND: C1.2, C1-EP-DR.2, C2.2, C3.2, C4.2, C5.2, C6.2, C7.2, C8.2, C9.2, C10.2, C11.2, C12.2, C13.2, C14.2, C15.2, C16.2, C17.1, C18.1, C19.1, C20.2, C21.2, C22.2, C23.1, C24.1, C25.2, C27.1, C29.1, C30.1, C31.1, C32.1, C33.2, C34.1, C37.1, C38.1, C39.2, C42.2, C43.2, D3.2 (GND), D4.1 (K), EPD_C1.1, EPD_C2.1, EPD_C5.1, EPD_C6.1, EPD_C7.1, EPD_C8.1, EPD_C9.1, EPD_C10.1, EPD_C11.1, EPD_C12.1, IC1.D2 (GND), IC2.B1 (IN/TRIG), IC2.B3 (GND), IC3.8 (GNDIO), IC3.9 (GND), IC9.B1 (VSEL), IC9.C1 (AGND), IC9.C2 (PGND_1), IC9.C3 (PGND_2), J1.8, J1.17, J1.MP1, J1.MP2, J2.3, J2.5, J4.A1_B12 (GND), J4.A12_B1 (GND), J4.SH1 (SHIELD), J4.SH2 (SHIELD), J4.SH3 (SHIELD), J4.SH4 (SHIELD), R1_USB.1, R2_EP_DR.1, R2_USB.2, R3.1, R9.1, R_TYPE_SEL.1, SJ1.1, SW_DN.1, SW_ENT.1, SW_UP.1, TP_BAT_GND.TP, TP_GND.TP, U1.P$74 (VSS_PAD), U1.P$75 (VSS_PAD), U1.P$76 (VSS_PAD), U1.P$77 (VSS_PAD), U1.P$78 (VSS_PAD), U1.P$79 (VSS_PAD), U1.P$80 (VSS_PAD), U1.P$81 (VSS_PAD), U1.P$82 (VSS_PAD), U1.P$83 (VSS_PAD), U1.P$84 (VSS_PAD), U1.P$85 (VSS_PAD), U1.P$86 (VSS_PAD), U1.P$87 (VSS_PAD), U1.P$88 (VSS_PAD), U1.P$89 (VSS_PAD), U1.P$90 (VSS_PAD), U1.P$B7 (VSS), U1.P$F23 (VSS_PA), U3.1 (CTG), U3.4 (GND), U3.6 (QSTRT), U3.9 (EP), X1.2, X1.4
HAPTIC_EN: IC2.A1 (EN), U1.P$U1 (P0.12)
IMU_INT1: IC3.5 (INT1), U1.P$N1 (P0.08)
IMU_INT2: IC3.6 (INT2), U1.P$P2 (P1.08)
LX1: IC9.B2 (SW1_1), IC9.B3 (SW1_2), L7.1
LX2: IC9.D2 (SW2_1), IC9.D3 (SW2_2), L7.2
MOSI: J1.14, U1.P$B13 (P0.03/AIN1)
unnamed: C5.1, U1.P$C1 (DEC1)
unnamed: C3.1, L1.1, U1.P$H23 (ANT)
unnamed: C20.1, U1.P$AC5 (DEC3V3)
unnamed: IC1.D1 (TS/MR), R9.2
unnamed: C2-EP-DR.2, D5.2 (A), L5.1, Q3.3 (D)
unnamed: C2-EP-DR.1, D2.1 (K), D4.2 (A)
unnamed: IC9.D1 (SCL), R4.2
unnamed: IC9.E1 (SDA), R2.2
unnamed: IC3.1 (SDO), R3.2
unnamed: J4.A5 (CC1), R1_USB.2
unnamed: EPD_C2.2, J1.4
unnamed: EPD_C1.2, J1.5
unnamed: R1_EP_DR.1, R_TYPE_SEL.2, SJ1.2
unnamed: J4.B5 (CC2), R2_USB.1
unnamed: C32.2, IC2.A2 (REG)
unnamed: EPD_C6.2, J1.18
unnamed: EPD_C7.2, J1.19
unnamed: EPD_C8.2, J1.20
unnamed: EPD_C10.2, J1.22
unnamed: EPD_C12.2, J1.24
unnamed: C9.1, U1.P$N24 (DEC5)
unnamed: C1.1, U1.P$B24 (XC1), X1.1
unnamed: C2.1, U1.P$A23 (XC2), X1.3
unnamed: C13.1, U1.P$A18 (DEC2)
unnamed: L2.2, L3.1
unnamed: L2.1, U1.P$B3 (DCC)
OUT+: IC2.A3 (OUT+), TP_OP.TP
OUT-: IC2.C3 (OUT-), TP_ON.TP
P0.00: C17.2, U1.P$D2 (P0.00/XL1), X2.2
P0.01: C18.2, U1.P$F2 (P0.01/XL2), X2.1
P0.04: U1.P$J1 (P0.04/AIN2)
P0.09: U1.P$L24 (P0.09/NFC1)
P0.13: C30.2, R5.1, SW_UP.2, U1.P$AD8 (P0.13)
P0.14: C31.2, R8.1, SW_ENT.2, U1.P$AC9 (P0.14)
P0.19: U1.P$AC15 (P0.19)
P0.20: U1.P$AD16 (P0.20)
P0.21: U1.P$AC17 (P0.21)
P0.22: U1.P$AD18 (P0.22)
P0.23: U1.P$AC19 (P0.23)
P0.24: U1.P$AD20 (P0.24)
P0.25: U1.P$AC21 (P0.25)
P0.26: U1.P$G1 (P0.26)
P0.27: U1.P$H2 (P0.27)
P0.28: U1.P$B11 (P0.28/AIN4)
P0.29: U1.P$A10 (P0.29/AIN5)
P0.30: U1.P$B9 (P0.30/AIN6)
P0.31: U1.P$A8 (P0.31/AIN7)
P1.01: Q1.1 (G), R_PWR_EPD.1, U1.P$Y23 (P1.01)
P1.02: C29.2, R7.1, SW_DN.2, U1.P$W24 (P1.02)
P1.03: U1.P$V23 (P1.03)
P1.04: U1.P$U24 (P1.04)
P1.05: U1.P$T23 (P1.05)
P1.06: U1.P$R24 (P1.06)
P1.07: U1.P$P23 (P1.07)
P1.09: U1.P$R1 (P1.09)
P1.10: U1.P$A20 (P1.10)
P1.11: U1.P$B19 (P1.11)
P1.12: U1.P$B17 (P1.12)
P1.13: U1.P$A16 (P1.13)
P1.14: U1.P$B15 (P1.14)
P1.15: U1.P$A14 (P1.15)
PMIC_INT: IC1.A1 (!INT), U1.P$T2 (P0.11)
PREVGH: D5.1 (K), EPD_C9.2, J1.21
PREVGL: D2.2 (A), EPD_C11.2, J1.23
RESE: J1.3, Q3.2 (S), R1_EP_DR.2
RESET: J2.6, TP_RESET.TP, U1.P$AC13 (P0.18/RESET)
RF: ANT1.1 (FEED), C4.1, C22.1, L1.2
SCK: J1.13, U1.P$A12 (P0.02/AIN0)
SCL: IC1.B1 (SCL), IC2.C1 (SCL), IC3.12 (SCX), R4.1, R17.1, TP_SCL.TP, U1.P$M2 (P0.07), U3.7 (SCL)
SDA: IC1.C1 (SDA), IC2.B2 (SDA), IC3.2 (SDX), R2.1, R18.1, TP_SDA.TP, U1.P$L1 (P0.06), U3.8 (SDA)
SWDCLK: J2.4, TP_SWDCLK.TP, U1.P$AA24 (SWDCLK)
SWDIO: J2.2, TP_SWDIO.TP, U1.P$AC24 (SWDIO)
SWO: TP_SWO.TP, U1.P$AD22 (P1.00)
VBAT: C27.2, C37.2, IC1.C2 (BAT), TP_VBAT.TP, U3.2 (CELL), U3.3 (VDD)
VBUS: C21.1, C38.2, C42.1, C43.1, D3.5 (VBUS), IC1.A2 (IN), J4.A4_B9 (VBUS), J4.A9_B4 (VBUS), U1.P$AD2 (VBUS)
VREG: C23.2, C24.2, C39.1, IC1.B2 (SYS), IC9.A1 (EN), IC9.A2 (VIN_1), IC9.A3 (VIN_2), TP_VREG.TP

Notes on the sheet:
LiPo Charger
DC/DC
IMU
SWD
E-Paper Drive Circuit
E-Paper Display Connector
Fuel Gauge
Haptic Drive
Buttons
USB C Connector & ESD Protection

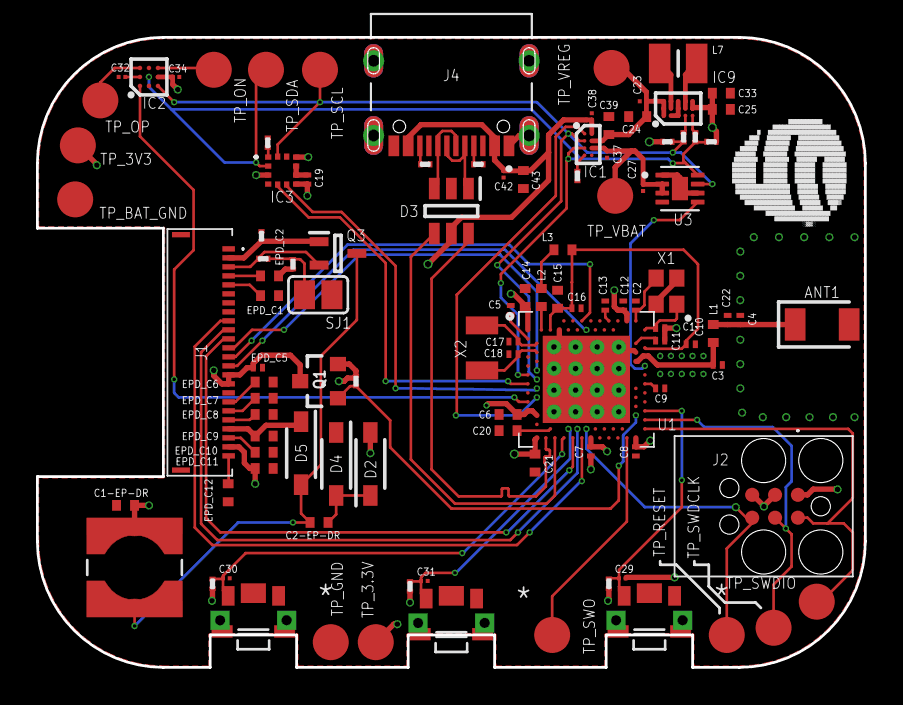
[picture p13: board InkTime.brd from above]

Board: 4 copper layers, 46.0 x 35.0 mm, 105 parts (0 on the bottom side), 70 nets.

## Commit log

2026-04-21 Add Readme, needa update board
    [InkTime.brd]
2026-04-21 images and readme update
    [InkTime.sch]

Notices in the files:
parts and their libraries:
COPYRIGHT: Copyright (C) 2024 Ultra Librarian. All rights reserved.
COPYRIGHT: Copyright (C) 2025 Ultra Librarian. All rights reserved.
